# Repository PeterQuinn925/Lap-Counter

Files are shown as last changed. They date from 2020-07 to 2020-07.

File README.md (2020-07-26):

# Lap-Counter

This project is a device to count laps when swimming. It uses an ultrasonic sensor to detect the swimmer and counts 50 yds/meters (out and back of a short course standard swimming pool. It calls out the distance on a speaker and shows on a 4 digit 7 seg LED. 

The container is a reused takeout container. I poked some holes in it for the ultrasonic "eyes" and put a couple of rolls of pennies in the bottom for ballast. It's ugly for sure.

Right now the volume on the speaker is still pretty low, even with the amp. It's also much noisier with the addition of the LED. I'm considering adding capacitors to reduce the noise or even getting rid of the speaker entirely. Other future considerations is to show the elapse time and the lap time - but I'm not sure what the best way to do that is. Future version may display the time also or transmit distance/time to a smart watch.

Uses: https://github.com/going-digital/Talkie for speech synth calling out the numbers
Adafruit librarys for LED display.

### Parts:
1. Generic Arduino Nano clone
2. Ultrasonic Sensor HC-SR04
3. Mono Amp
   SparkFun Mono Audio Amp Breakout - TPA2005D1
   https://www.sparkfun.com/tutorials/392  
4. Battery Charger Board
   SparkFun LiPo Charger Basic - Micro-USB
5. LiPo Battery - Lithium Ion Battery - 400mAh
6. Battery Booster  https://www.adafruit.com/product/4654 (3v to 5v)
7. 4 digit 7 seg LED. With controlling circuit. https://www.adafruit.com/product/878
8. Momentary Switch
9. On/Off toggle switch
10. 8-ohm Speaker (salvaged) 

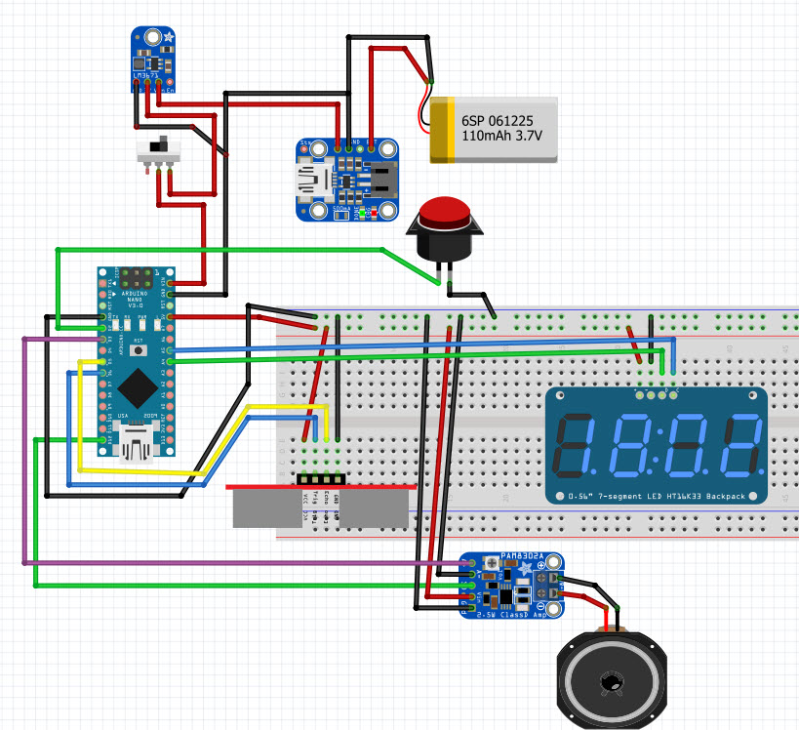
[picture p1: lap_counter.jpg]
Fritzing Jpg

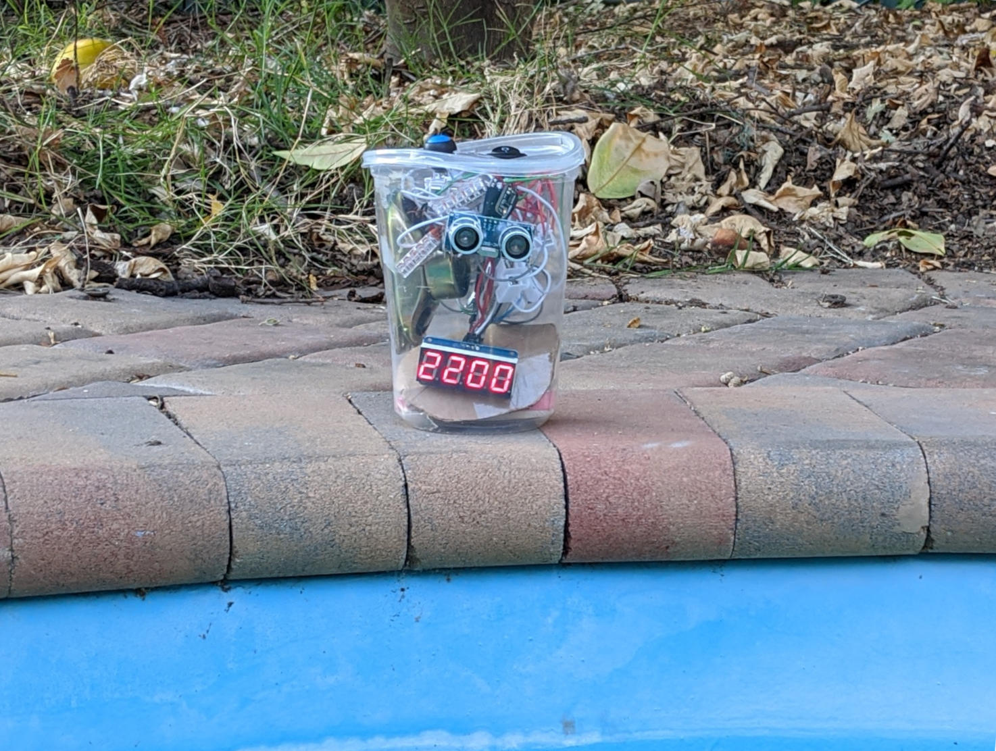
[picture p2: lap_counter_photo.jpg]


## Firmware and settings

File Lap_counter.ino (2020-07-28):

#define echoPin 5 // attach pin D5 Arduino to pin Echo of HC-SR04
#define trigPin 6 //attach pin D6 Arduino to pin Trig of HC-SR04
#define amponPin 12 //attach pin D12 to the SD pin of amp to control power saving
#define interruptPin 2 // attach interrupt switch to pin D2
#include "Talkie.h"
#include "Vocab_US_Large.h"
#include <Wire.h> // Enable this line if using Arduino Uno, Mega, etc.
#include <Adafruit_GFX.h>
#include "Adafruit_LEDBackpack.h"
//Pin A4 to DAT on LED
//Pin A5 to CLK on LED
Adafruit_7segment matrix = Adafruit_7segment();
//talkie uses digital pin 3
Talkie voice;
//const byte interruptPin = 2;
volatile boolean restart_now = true;

// defines variables
unsigned long start_time;
unsigned long last_lap_t;
int lap_count;
int yards;
float ave_time;
unsigned long min_lap_t = 40000; //40 seconds = 40000
unsigned long current_t;
int d1;//debugging
int num_ave = 3; //average this number of distance readings
int min_distance = 75;

void setup() {
  pinMode(trigPin, OUTPUT); // Sets the trigPin as an OUTPUT
  pinMode(echoPin, INPUT); // Sets the echoPin as an INPUT
  pinMode(interruptPin, INPUT_PULLUP);
  pinMode(amponPin, OUTPUT);
  attachInterrupt(digitalPinToInterrupt(interruptPin), restart, LOW);
  Serial.begin(9600); // // Serial Communication is starting with 9600 of baudrate speed
  matrix.begin(0x70);
  start_time = millis();
  last_lap_t = start_time;
}

void loop() {
  int yards;
  if (restart_now) {//Interrupt just finished, reset all times
    restart_now = false;
    digitalWrite(amponPin, HIGH); // turn on the amp
    Serial.println("amp on");
    voice.say(sp4_READY);
    voice.say(sp2_TWO);
    voice.say(sp4_START);
    delay(1000);
    matrix.println(333, DEC);
    matrix.writeDisplay();
    voice.say(sp2_THREE);
    delay(500);
    matrix.println(22, DEC);
    matrix.writeDisplay();
    voice.say(sp2_TWO);
    delay(500);
    matrix.println(1, DEC);
    matrix.writeDisplay();
    voice.say(sp2_ONE);
    delay(500);
    matrix.println(0000, DEC);
    matrix.writeDisplay();
    voice.say(sp2_GO);
    digitalWrite(amponPin, LOW); // turn off the amp
    Serial.println("amp off");
    delay(100);
    restart_now = false;//for some reason it's running twice. This cures it.
    start_time = millis();
    last_lap_t = start_time;
    lap_count = 0;
    yards = 0;
    ave_time = 0;
    Serial.println("Lap Counter");
  }
  current_t = millis();

  //Serial.println(current_t -last_lap_t);
  if (GetDist() < min_distance && (current_t - last_lap_t > min_lap_t))
  {
    lap_count++;
    yards = lap_count * 50;
    do {
      Serial.print("Distance:");
      Serial.println(yards);
      Serial.print("Elapsed time: "); \
      Serial.println(TimeToString(millis() - start_time));
      Serial.print("Lap time: ");
      Serial.println(TimeToString(millis() - last_lap_t));
      matrix.println(yards);
      matrix.writeDisplay();
      CallLap(yards);
      delay(3000);
    }
    while (GetDist() < min_distance);
    last_lap_t = millis();
  }
}

int GetDist()
{
  long duration; // variable for the duration of sound wave travel
  int distance; // variable for the distance measurement
  int sum_dist = 0; // average distance intermediate
  d1++;
  for (int i = 1; i <= num_ave; i++)
  {
    //Serial.println("GetDist()");
    digitalWrite(trigPin, LOW);
    delayMicroseconds(2);
    // Sets the trigPin HIGH (ACTIVE) for 10 microseconds
    digitalWrite(trigPin, HIGH);
    delayMicroseconds(10);
    digitalWrite(trigPin, LOW);
    // Reads the echoPin, returns the sound wave travel time in microseconds
    duration = pulseIn(echoPin, HIGH);
    // Calculating the distance
    distance = duration * 0.034 / 2; // Speed of sound wave divided by 2 (go and back)
    sum_dist = sum_dist + distance;
  }
  distance = sum_dist / num_ave;
  if (d1 % 50 == 0) {
    Serial.println(distance);
  }
  return distance;
}

// t is time in miliseconds
char * TimeToString(unsigned long t)
{
  static char str[12];
  t = t / 1000; //convert t to seconds
  long h = t / 3600;
  t = t % 3600;
  int m = t / 60;
  int s = t % 60;
  sprintf(str, "%02d:%02d", m, s);
  //sprintf(str, "%04ld:%02d:%02d", h, m, s);
  return str;
}

void CallLap(int dist) //expects 100, 150, 200, 250, etc
{
  int hund = dist / 100 ; //number of hundreds
  int fifty = (dist % 100) / 50; //0 if even hundred, 1 if a 50
  int thou = dist / 1000 ; // will call out thousands differently

  digitalWrite(amponPin, HIGH); // turn on the amp
  Serial.println("amp on");
  //for 100 - 900 just say n hundred, for the 50s, just add on 50
  //for 1100 - 1950 do the same
  if (dist < 1000 || (dist >= 1100 && dist <= 1950)) {

    if (hund > 0) {
      SayNum(hund);
    }
    if (fifty > 0) {
      voice.say(sp3_FIFTY);
    }
    else
    {
      voice.say(sp3_HUNDRED);
    }
  }
  //if equal to an even thousand or thousand 50
  else if (dist % 1000 < 51)
  {
    SayNum(thou);
    voice.say(sp2_THOUSAND);
    if (fifty > 0) {
      voice.say(sp3_FIFTY);
    }
  }
  // for the 2100 - 2950 say 21 hundred, 22 hundred, 21 50, 22 50, etc
  else if (dist >= 2100 && dist <= 2950) {
    hund = (dist - 2000) / 100;
    String fnam1 = String(hund, DEC);
    String fnam2 = String(fnam1 + ".wav");
    voice.say(sp2_TWENTY);
    SayNum(hund);
    if (fifty > 0) {
      voice.say(sp3_FIFTY);
    }
    else
    {
      voice.say(sp3_HUNDRED);
    }
  }
  else {  //more than 3000
    SayNum(thou);
    voice.say(sp2_THOUSAND);

    if (hund > 0) {
      hund = hund - thou * 10;
      SayNum(hund);
    }
    if (fifty > 0) {
      voice.say(sp3_FIFTY);
    }
    else
    {
      voice.say(sp3_HUNDRED);
    }
  }
  digitalWrite(amponPin, LOW); // turn off the amp
  Serial.println("amp off");
}


void SayNum(int num)
{
  Serial.println(num);
  switch (num)
  {
    case 1:
      voice.say(sp3_ONE);
      break;
    case 2:
      voice.say(sp3_TWO);
      break;
    case 3:
      voice.say(sp3_THREE);
      break;
    case 4:
      voice.say(sp3_FOUR);
      break;
    case 5:
      voice.say(sp3_FIVE);
      break;
    case 6:
      voice.say(sp3_SIX);
      break;
    case 7:
      voice.say(sp3_SEVEN);
      break;
    case 8:
      voice.say(sp3_EIGHT);
      break;
    case 9:
      voice.say(sp3_NINE);
      break;
    case 11://skip 10 - this is a special case
      voice.say(sp3_ELEVEN);
      break;
    case 12:
      voice.say(sp3_TWELVE);
      break;
    case 13:
      voice.say(sp3_THIRTEEN);
      break;
    case 14:
      voice.say(sp3_FOURTEEN);
      break;
    case 15:
      voice.say(sp3_FIFTEEN);
      break;
    case 16:
      voice.say(sp3_SIXTEEN);
      break;
    case 17:
      voice.say(sp3_SEVENTEEN);
      break;
    case 18:
      voice.say(sp3_EIGHTEEN);
      break;
    case 19:
      voice.say(sp3_NINETEEN);
      break;
    case 20:
      voice.say(sp3_TWENTY);
      break;
    default:
      voice.say(sp3_ERROR);
      break;
  }
}
void restart() {//restart on pin2 brought low
  restart_now = true;
}

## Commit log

2020-07-12 Fritzing schematic
    [lapcounter.fzz]
2020-07-12 schematic overview (missing the shutdown pin)
2020-07-12 added amp shutdown pin to D12
    [lapcounter.fzz]
2020-07-12 updated with shutdown pin
2020-07-25 With display
    [lapcounter.fzz]
2020-07-25 added battery booster and 7seg LED
2020-07-25 added 7seg and battery booster
2020-07-25 Add 7seg LED
2020-07-26 Whoops forgot the ultrasonic sensor in the parts list
2020-08-08 Removed voice, added elapsed time to display
    Removed all code having to do with the voice. Removed the amp and voice related circuitry. Added the elapsed time to alternate with the lap counter in the LED display.
